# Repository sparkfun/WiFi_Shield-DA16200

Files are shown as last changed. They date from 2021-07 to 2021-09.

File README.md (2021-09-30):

SparkFun WiFi Shield DA16200
========================================

SparkFun WiFi Shield DA16200

[*SparkFun WiFi Shield DA16200 (18567)*](https://www.sparkfun.com/products/18567)

Ultra. Low. Power. Arguably the best three words in the IoT world. SparkFun has teamed up with ARM and Dialog to provide you with this WiFi Shield based around the DA16200 module. The DA16200 is a fully integrated WiFi module with a 40MHz crystal oscillator, 32.768KHz RTC clock, RF Lumped RF filter, 4MB flash memory, and an onboard chip antenna. With the addition of a Qwiic connector, multiple GPIO options, JTAG connectors for deep dive programming, and you've got everything you need to get your R3 layout device ready to set up your next IoT project. 

The SparkFun Qwiic WiFi Shield is ideal for door locks, thermostats, sensors, pet trackers, and other home IoT projects, thanks in part to the multiple sleep modes that allow you to take advantage of current draws as low as 0.2uA-3.5uA.  

Additionally, the DA16200 module's certified WiFi alliance for IEEE802.11b/g/n, WiFi Direct, and WPS functionalities means that it has been approved for use by multiple countries and using the WiFi Alliance transfer policy, each WiFi Certification can be transferred without being tested again. 

Repository Contents
-------------------

* **/Hardware** - Eagle design files (.brd, .sch)

Documentation
--------------
* **[Hookup Guide](https://sparkle.sparkfun.com/sparkle/learn_tutorials/1991)** - Basic hookup guide for the SparkFun WiFi Shield DA16200.

License Information
-------------------

This product is _**open source**_! 

Please review the LICENSE.md file for license information. 

If you have any questions or concerns on licensing, please contact technical support on our [SparkFun forums](https://forum.sparkfun.com/viewforum.php?f=152).

Distributed as-is; no warranty is given.

- Your friends at SparkFun.

_<COLLABORATION CREDIT>_

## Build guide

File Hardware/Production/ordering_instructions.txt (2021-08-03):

panel size, 194x115mm
PCB thickness, 1.6mm
number of layers, 2
soldermask color, Red
silkscreen color, White
oz copper, 1oz
finish, HASL lead free
stencils, top
pcs per panel, 6
min trace width, 0.2032mm / 0.0080in
min drill size, 0.3048mm / 0.0120in

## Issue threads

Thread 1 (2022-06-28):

How to update the firmware?

KeilChris, 2022-06-28:
Hello,
Dialog have released a new FW for the module. Unfortunately, I'm not able to update it on the shield. I have soldered pin headers to "DA16200 PROG" and can kind of connect to the board (I see the serial console), but I cannot use the provided TeraTerm scripts as the required reset never happens. Did anyone update the FW successfully?

KeilChris, 2022-06-28:
Hm, another try today and it worked. Sorry for the confusion!

Closed 2022-06-28.

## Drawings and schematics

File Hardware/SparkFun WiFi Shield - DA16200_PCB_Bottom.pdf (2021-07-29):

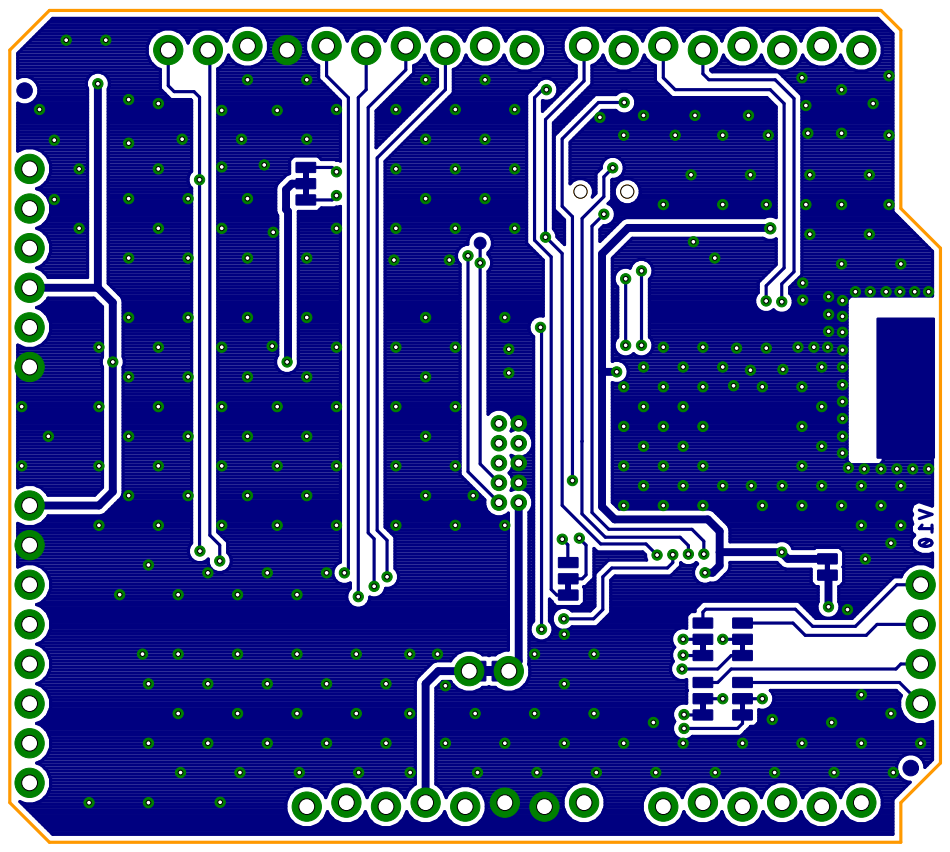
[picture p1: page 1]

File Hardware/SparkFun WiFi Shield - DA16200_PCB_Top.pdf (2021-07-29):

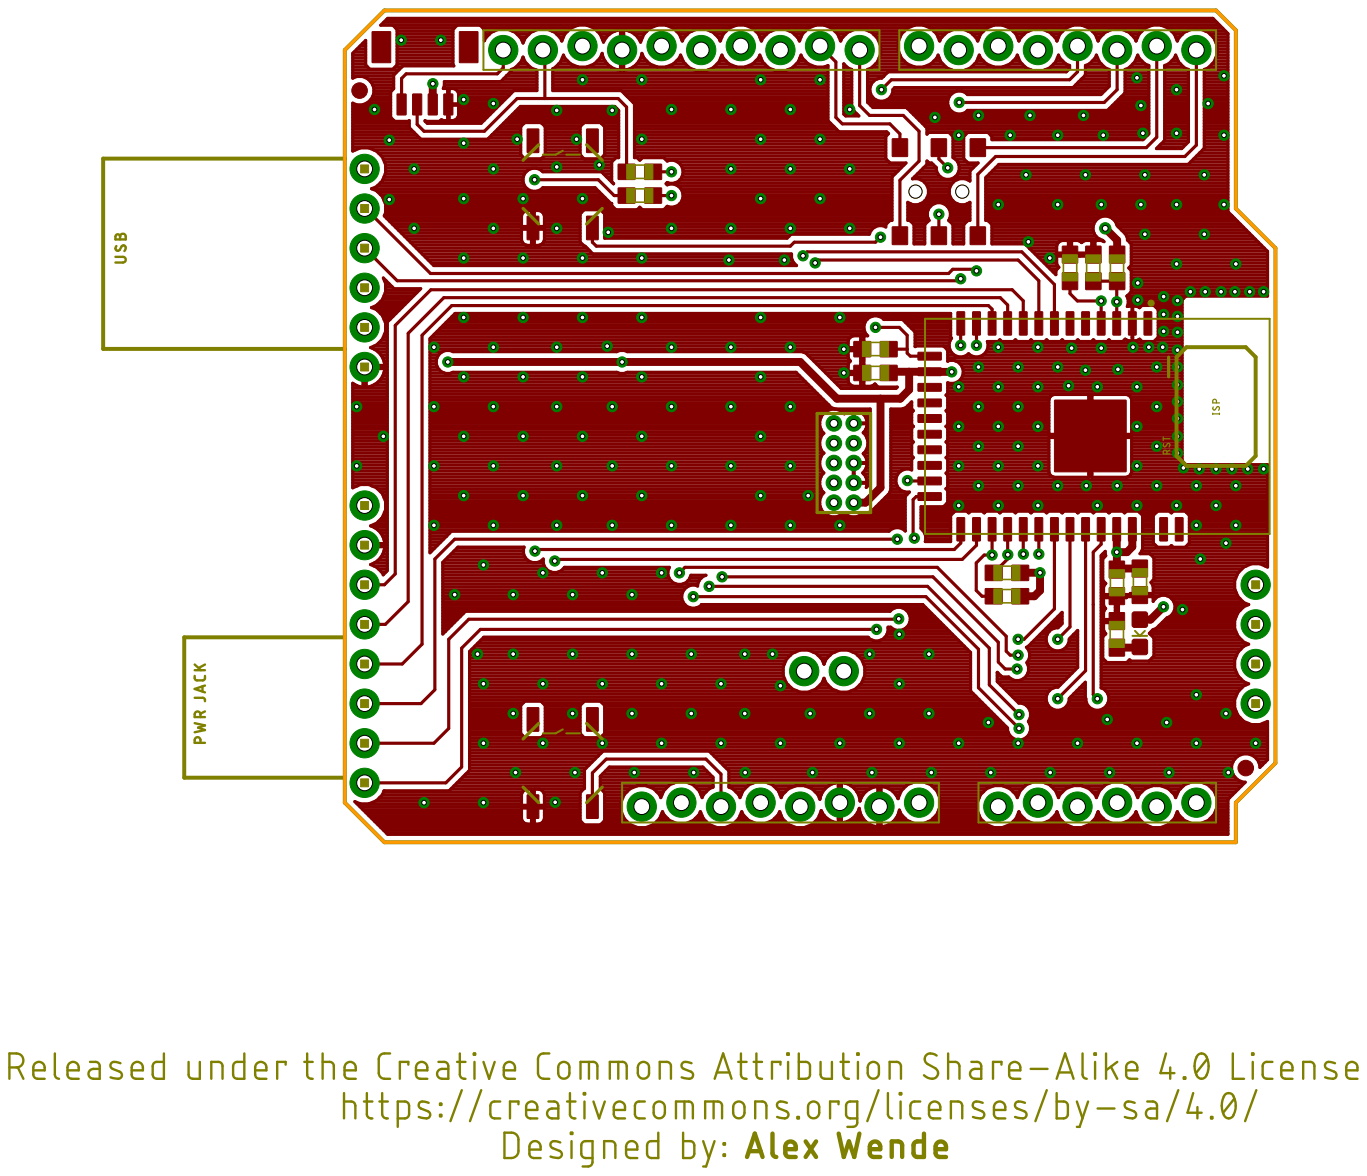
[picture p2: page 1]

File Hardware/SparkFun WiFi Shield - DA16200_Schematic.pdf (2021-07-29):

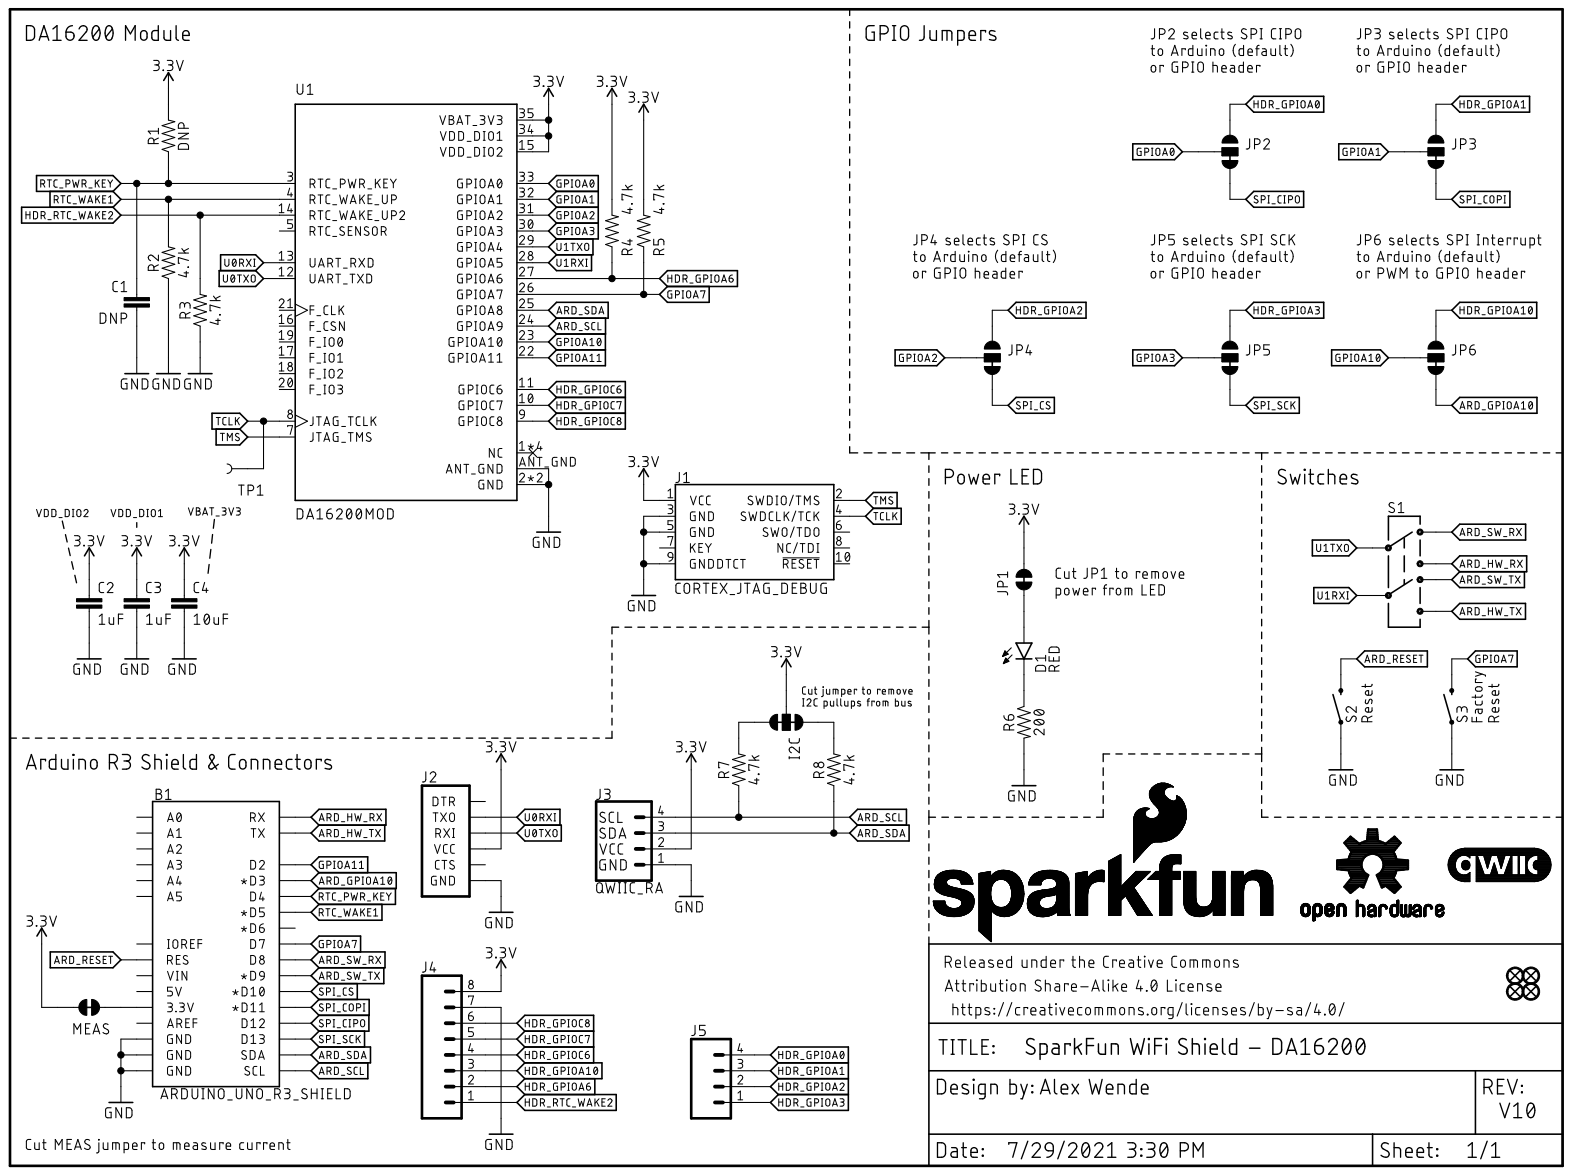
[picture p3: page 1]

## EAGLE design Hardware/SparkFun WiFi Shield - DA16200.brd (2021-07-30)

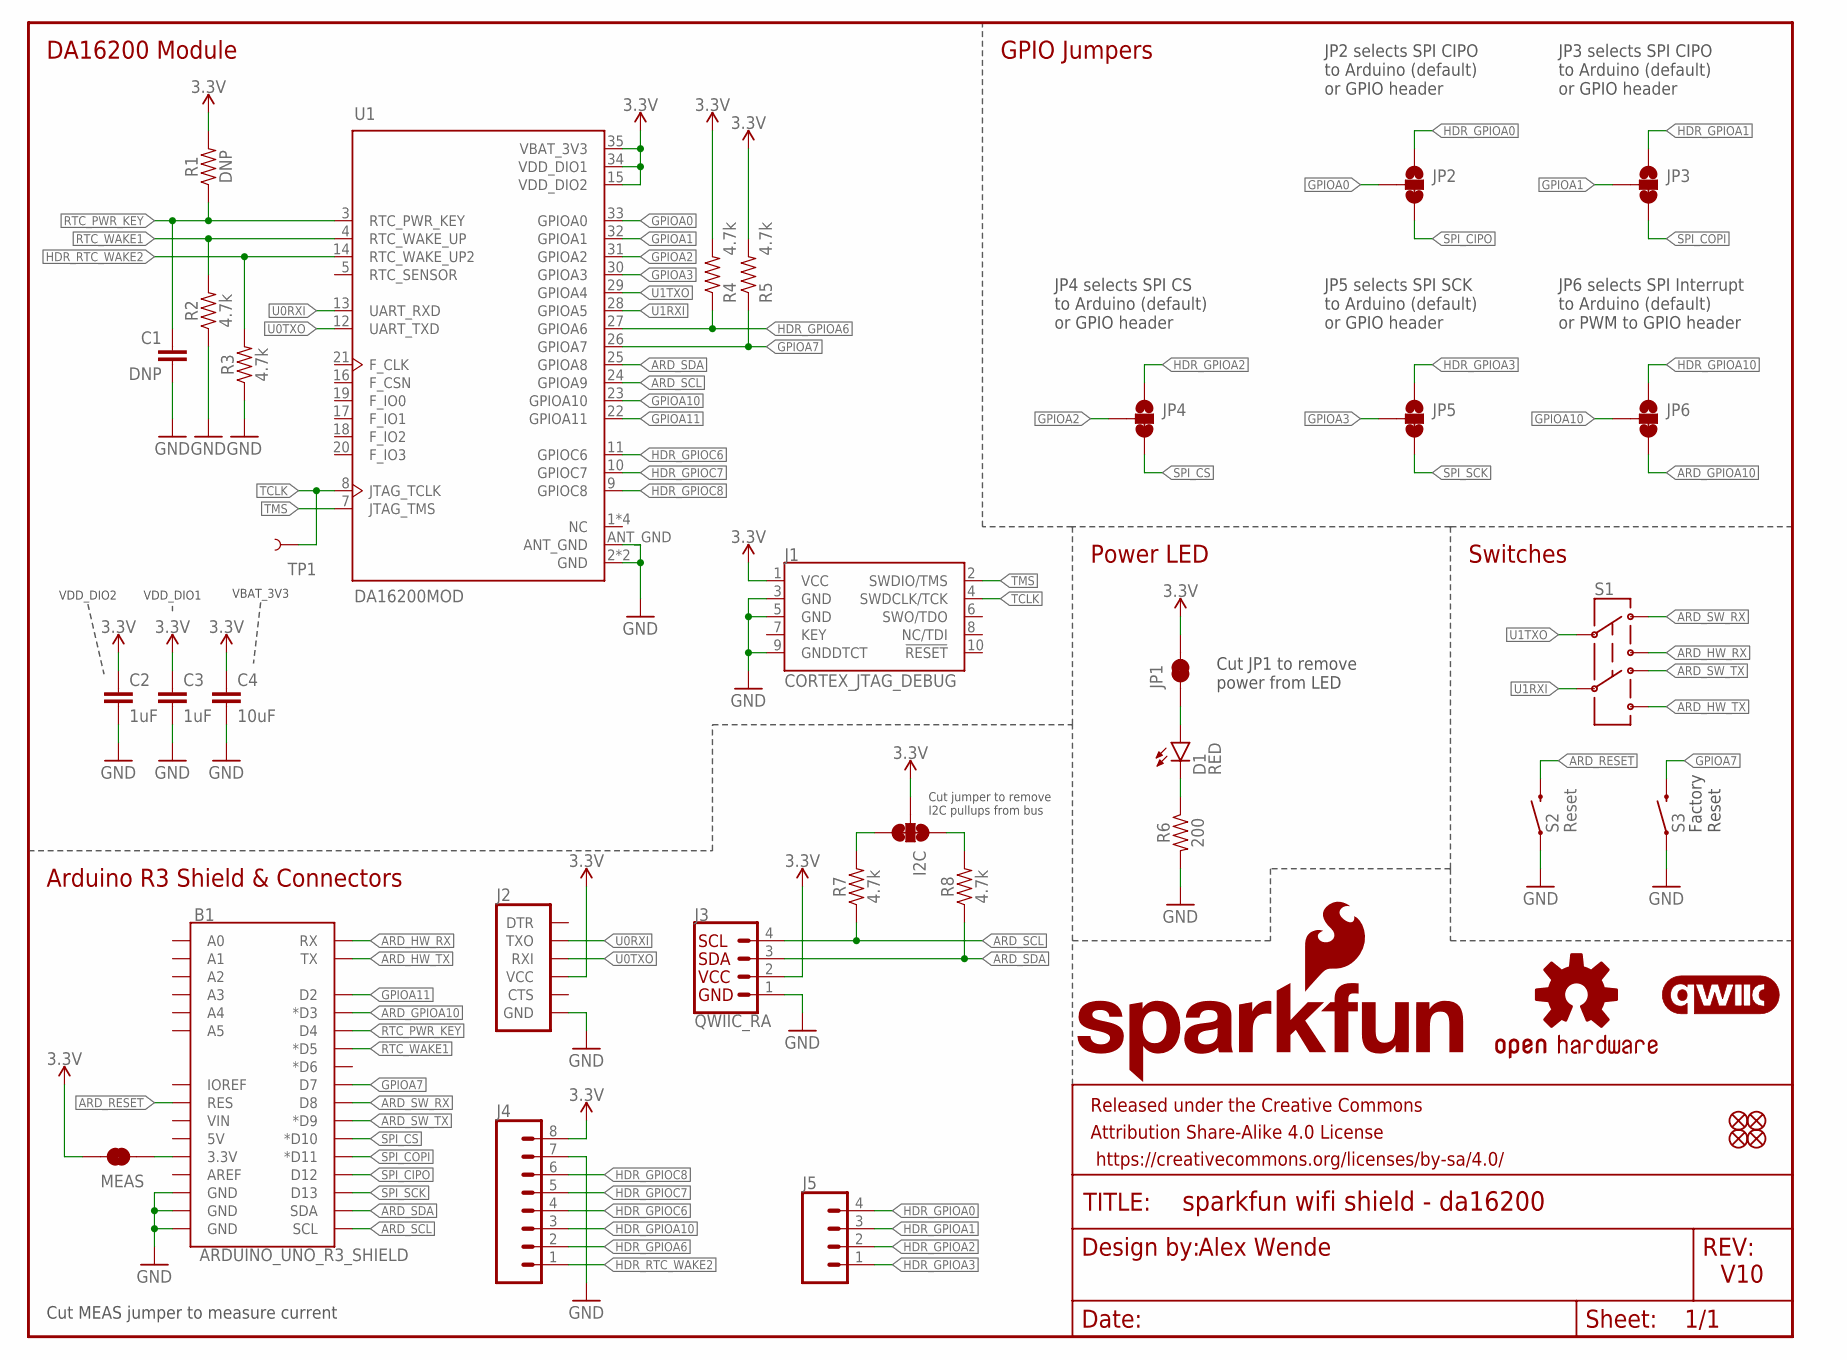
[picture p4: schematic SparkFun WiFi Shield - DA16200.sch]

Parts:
B1: ARDUINO_UNO_R3_SHIELD; UNO_R3_SHIELD_NOLABELS_LOCK
C1: DNP; 0603
C2, C3: 1uF; 0603
C4: 10uF; 0603
D1: RED; LED-0603
FD1, FD2, FD3, FD4: FIDUCIAL1X2; FIDUCIAL-1X2
FRAME1: FRAME-LETTER; CREATIVE_COMMONS
I2C: JUMPER-SMT_3_2-NC_TRACE_SILK; SMT-JUMPER_3_2-NC_TRACE_SILK
J1: CORTEX_JTAG_DEBUG; 2X5-PTH-1.27MM-NO_SILK
J2: 6_PIN_SERIAL_TARGET_NO_SILK; 1X06_NO_SILK
J3: QWIIC_RA; JST04_1MM_RA
J4: CONN_08NO_SILK_DNP; 1X08_NO_SILK
J5: CONN_041X04_NO_SILK; 1X04_NO_SILK
JP1: JUMPER-SMT_2_NC_TRACE_SILK; SMT-JUMPER_2_NC_TRACE_SILK
JP2, JP3, JP4, JP5, JP6: JUMPER-SMT_3_1-NC_TRACE_SILK; SMT-JUMPER_3_1-NC_TRACE_SILK
LOGO1: SFE_LOGO_NAME_FLAME.2_INCH; SFE_LOGO_NAME_FLAME_.2
LOGO2: OSHW-LOGOM; OSHW-LOGO-M
LOGO4: QWIIC_LOGO_5MM; QWIIC_5MM
MEAS: JUMPER-COMBO_2_NC_TRACE; COMBO-JUMPER_2_NC_TRACE
R1: DNP; 0603
R2, R3, R4, R5, R7, R8: 4.7k; 0603
R6: 200; 0603
S1: DPDT; SWITCH_DPDT_SMD_AYZ0202
S2: Reset; TACTILE_SWITCH_SMD_5.2MM
S3: MOMENTARY-SWITCH-SPST-SMD-5.2MM-TALL; TACTILE_SWITCH_SMD_5.2MM
TP1: TEST-POINT3; PAD.03X.03
U1: DA16200MOD; XCVR_DA16200MOD-AAC4WA32

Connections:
3.3V: C2.1, C3.1, C4.1, I2C.2, J1.1 (VCC), J2.4 (VCC), J3.2, J4.8, JP1.2, MEAS.1, MEAS.3 (1), R1.2, R4.2, R5.2, U1.15 (VDD_DIO2), U1.34 (VDD_DIO1), U1.35 (VBAT_3V3)
ARD_GPIOA10: B1.D3 (*D3), JP6.3
ARD_HW_RX: B1.RX, S1.1
ARD_HW_TX: B1.TX, S1.4
ARD_RESET: B1.RES, S2.3 (2)
ARD_SCL: B1.SCL, J3.4, R7.1, U1.24 (GPIOA9)
ARD_SDA: B1.SDA, J3.3, R8.1, U1.25 (GPIOA8)
ARD_SW_RX: B1.D8, S1.3
ARD_SW_TX: B1.D9 (*D9), S1.6
GND: B1.GND@0 (GND), B1.GND@1 (GND), B1.GND@2 (GND), C1.2, C2.2, C3.2, C4.2, J1.3 (GND), J1.5 (GND), J1.9 (GNDDTCT), J2.6 (GND), J3.1, J4.7, R2.1, R3.1, R6.2, S2.1, S3.1, U1.2 (GND), U1.ANT_GND, U1.GND
GPIOA0: JP2.2, U1.33 (GPIOA0)
GPIOA1: JP3.2, U1.32 (GPIOA1)
GPIOA2: JP4.2, U1.31 (GPIOA2)
GPIOA3: JP5.2, U1.30 (GPIOA3)
GPIOA7: B1.D7, R5.1, S3.3 (2), U1.26 (GPIOA7)
GPIOA10: JP6.2, U1.23 (GPIOA10)
GPIOA11: B1.D2, U1.22 (GPIOA11)
HDR_GPIOA0: J5.4, JP2.1
HDR_GPIOA1: J5.3, JP3.1
HDR_GPIOA2: J5.2, JP4.1
HDR_GPIOA3: J5.1, JP5.1
HDR_GPIOA6: J4.2, R4.1, U1.27 (GPIOA6)
HDR_GPIOA10: J4.3, JP6.1
HDR_GPIOC6: J4.4, U1.11 (GPIOC6)
HDR_GPIOC7: J4.5, U1.10 (GPIOC7)
HDR_GPIOC8: J4.6, U1.9 (GPIOC8)
HDR_RTC_WAKE2: J4.1, R3.2, U1.14 (RTC_WAKE_UP2)
unnamed: B1.3.3V, MEAS.2, MEAS.4 (2)
unnamed: D1.A, JP1.1
unnamed: I2C.3, R7.2
unnamed: I2C.1, R8.2
unnamed: D1.C, R6.1
RTC_PWR_KEY: B1.D4, C1.1, R1.1, U1.3 (RTC_PWR_KEY)
RTC_WAKE1: B1.D5 (*D5), R2.2, U1.4 (RTC_WAKE_UP)
SPI_CIPO: B1.D12, JP2.3
SPI_COPI: B1.D11 (*D11), JP3.3
SPI_CS: B1.D10 (*D10), JP4.3
SPI_SCK: B1.D13, JP5.3
TCLK: J1.4 (SWDCLK/TCK), TP1.1, U1.8 (JTAG_TCLK)
TMS: J1.2 (SWDIO/TMS), U1.7 (JTAG_TMS)
U0RXI: J2.3 (TXO), U1.13 (UART_RXD)
U0TXO: J2.2 (RXI), U1.12 (UART_TXD)
U1RXI: S1.5, U1.28 (GPIOA5)
U1TXO: S1.2, U1.29 (GPIOA4)

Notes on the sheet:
Factory Reset
DA16200 Module
Arduino R3 Shield & Connectors
Switches
V10
Alex Wende
VDD_DIO2
VDD_DIO1
VBAT_3V3
Power LED
GPIO Jumpers
Cut JP1 to remove power from LED
JP6 selects SPI Interrupt to Arduino (default) or PWM to GPIO header
Cut MEAS jumper to measure current
Cut jumper to remove I2C pullups from bus
JP2 selects SPI CIPO to Arduino (default) or GPIO header
JP3 selects SPI CIPO to Arduino (default) or GPIO header
JP4 selects SPI CS to Arduino (default) or GPIO header
JP5 selects SPI SCK to Arduino (default) or GPIO header

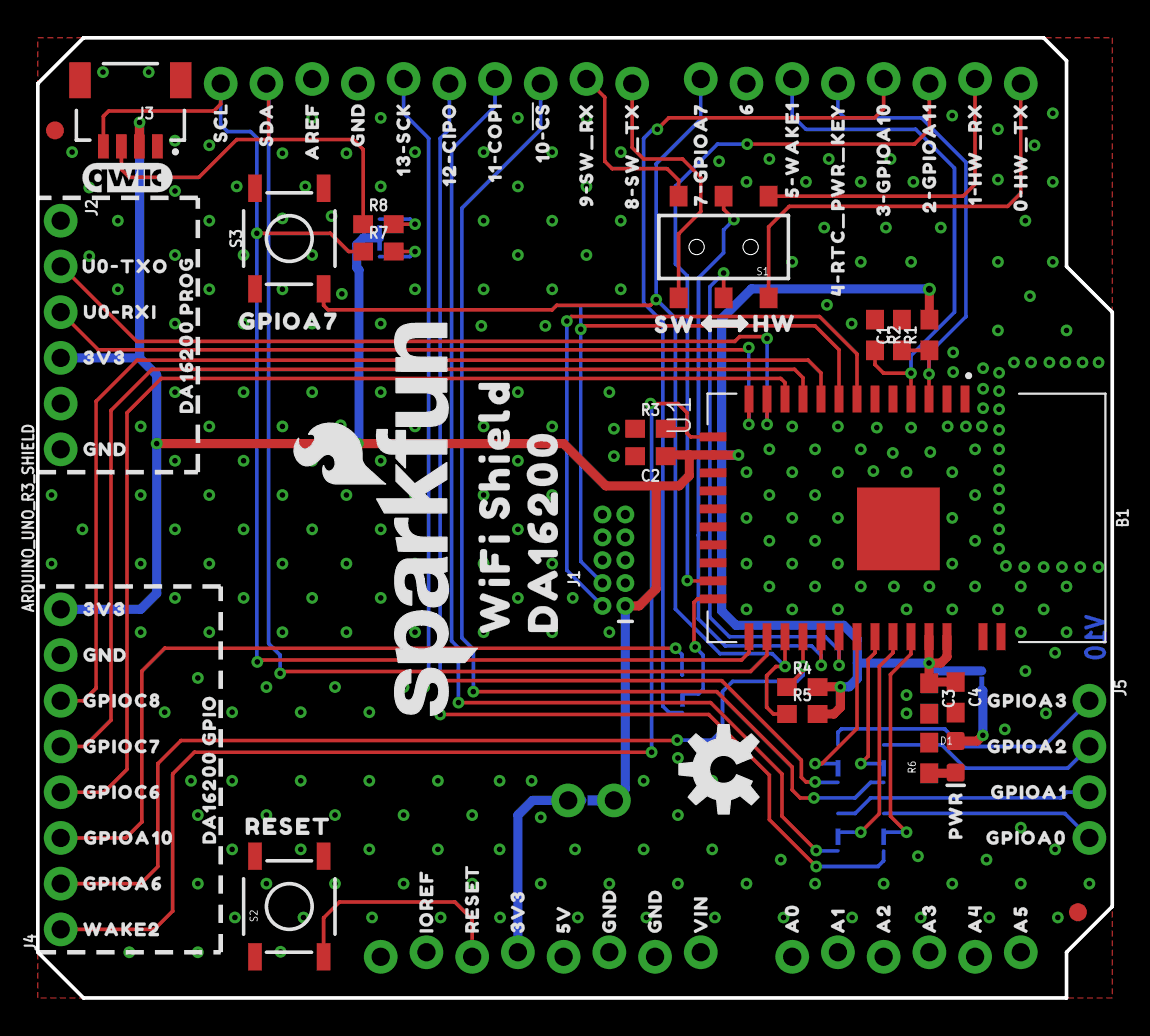
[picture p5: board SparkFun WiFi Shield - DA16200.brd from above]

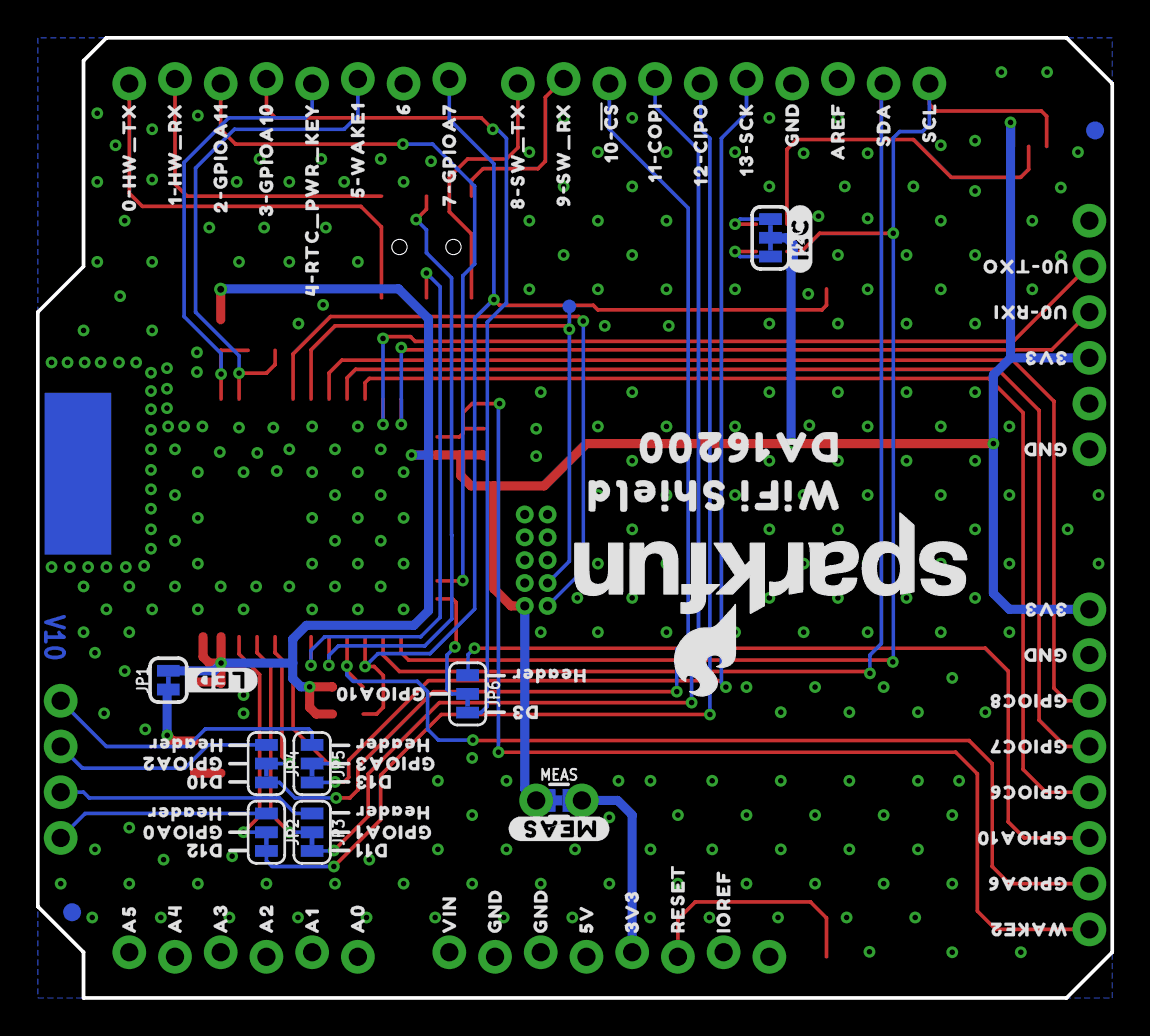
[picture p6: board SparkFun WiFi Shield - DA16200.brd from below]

Board: 2 copper layers, 59.7 x 53.3 mm, 160 parts (75 on the bottom side), 44 nets.

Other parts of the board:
LOGO3: SFE_LOGO_NAME_FLAME.2_INCH; SFE_LOGO_NAME_FLAME_.2
U$1, U$16: IOREF0
U$2, U$19: RESET0
U$3, U$37, U$39, U$41, U$85, U$87: 3V30
U$4, U$55: 5V0
U$5, U$6, U$28, U$40, U$52, U$56, U$57, U$79, U$86, U$88: GND0
U$7, U$58: VIN0
U$8, U$59: A00
U$9, U$60: A10
U$10, U$61: A20
U$11, U$62: A30
U$12, U$63: A40
U$13, U$64: A50
U$14, U$65: 0#HW_TX0
U$15, U$66: 1#HW_RX0
U$17, U$95: GPIOA60
U$18, U$70: 4#RTC_PWR_KEY0
U$20, U$73: 8#SW_TX0
U$21, U$72: 7#GPIOA70
U$23, U$33: 5#WAKE10
U$24, U$75: 10##CS#0
U$25, U$76: 11#COPI0
U$26, U$77: 12#CIPO0
U$27, U$78: 13#SCK0
U$29, U$80: AREF0
U$30, U$81: SDA0
U$31, U$82: SCL0
U$32, U$74: 9#SW_RX0
U$34: GPIOA70
U$35, U$48: WAKE20
U$36: RESET_0
U$38, U$71: 60
U$42: HW0
U$43: SW0
U$44, U$89: GPIOC80
U$45, U$90: GPIOC70
U$46, U$91: GPIOC60
U$47, U$69, U$92: GPIOA100
U$49: #I2C#0
U$50, U$109: 2#GPIOA110
U$51, U$68: 3#GPIOA100
U$53, U$83: U0#TXO0
U$54, U$84: U0#RXI0
U$93, U$115: GPIOA00
U$94, U$114: GPIOA10
U$96: D30
U$97: #LED#0
U$98: #MEAS#0
U$99: PWR0
U$100, U$107: WIFI_SHIELD0
U$101, U$108: DA162000
U$102, U$116: GPIOA20
U$103, U$117: GPIOA30
U$104: DA16200_GPIO0
U$105: DA16200_PROG0
U$106, U$118, U$119, U$120, U$121: HEADER0
U$122: D100
U$123: D110
U$124: D120
U$125: D130

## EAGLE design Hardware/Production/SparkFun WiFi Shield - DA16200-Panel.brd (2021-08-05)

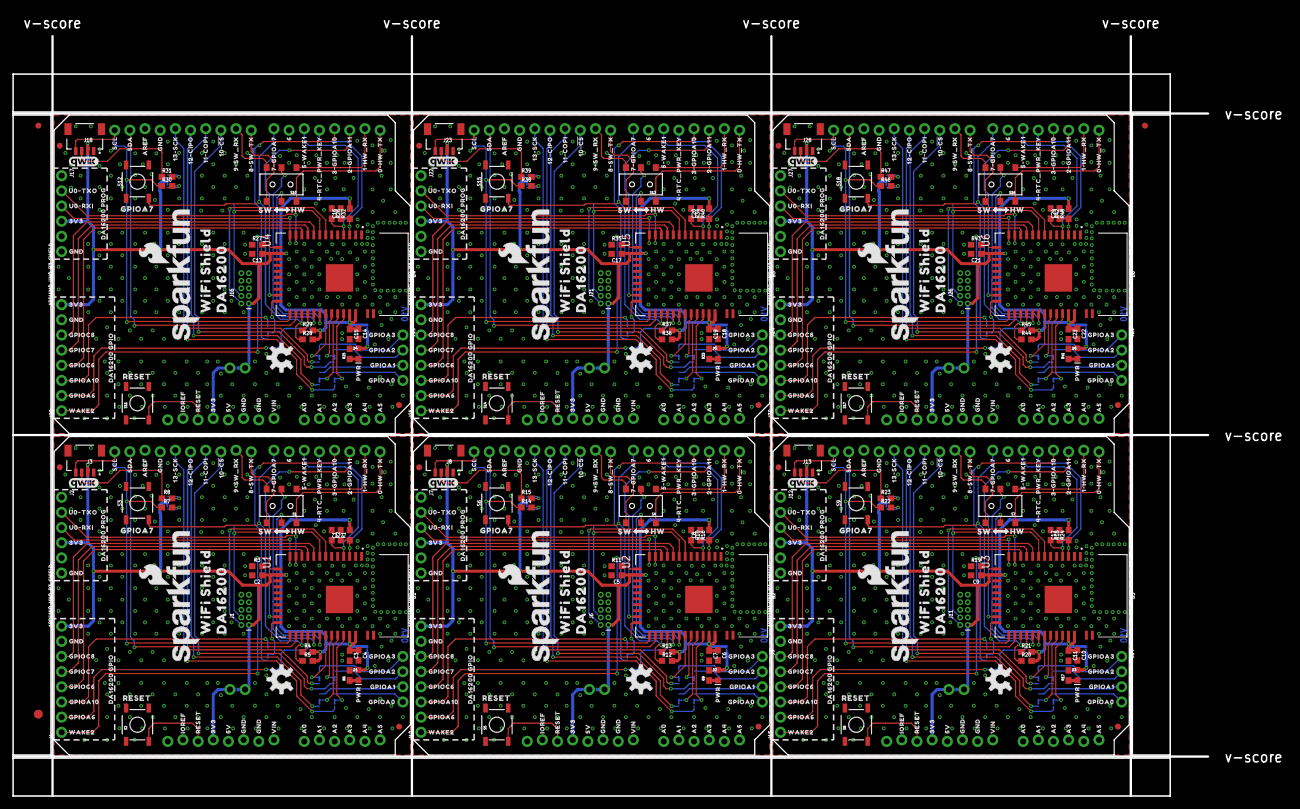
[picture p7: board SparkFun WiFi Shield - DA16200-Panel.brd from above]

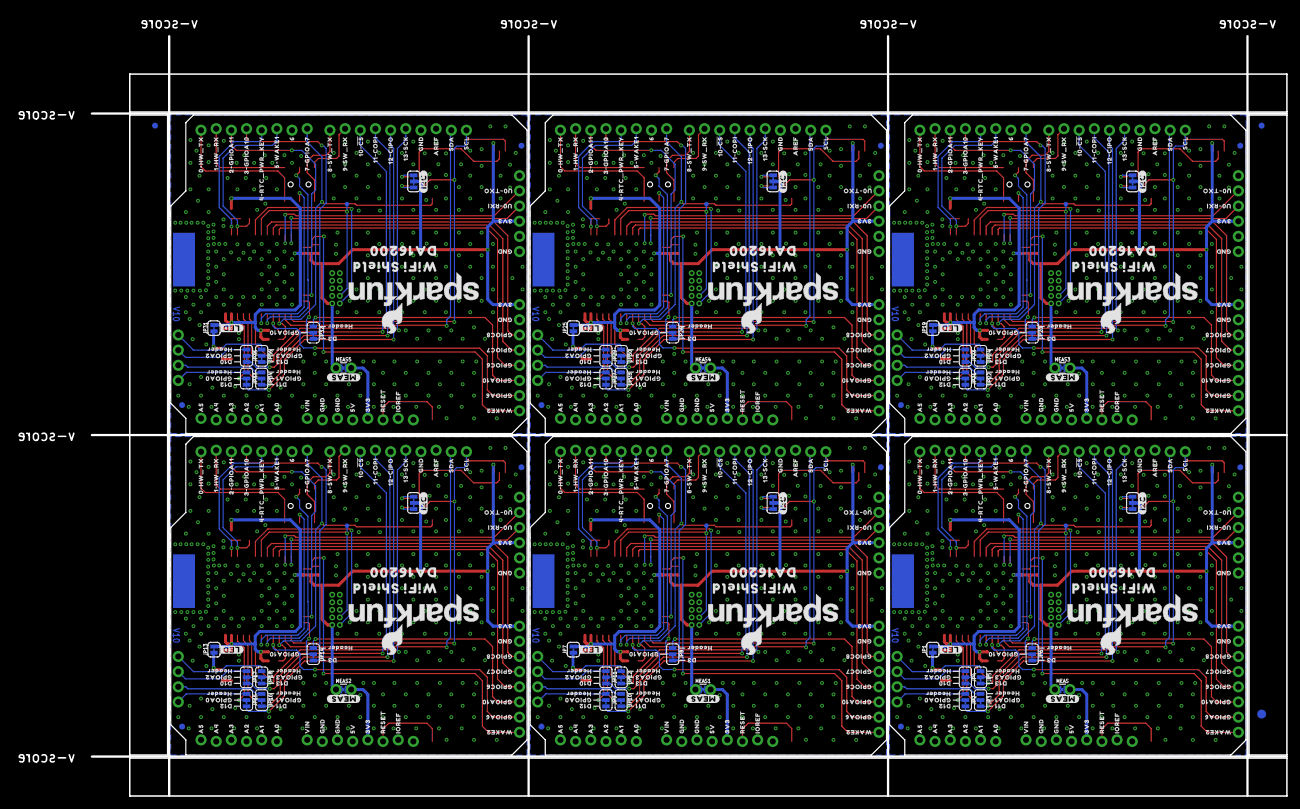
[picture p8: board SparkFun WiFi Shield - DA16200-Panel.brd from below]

Board: 2 copper layers, 200.2 x 127.3 mm, 960 parts (453 on the bottom side), 264 nets.

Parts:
B1, B2, B3, B4, B5, B6: ARDUINO_UNO_R3_SHIELD; UNO_R3_SHIELD_NOLABELS_LOCK
C1, C8, C12, C16, C20, C24: DNP; 0603
C2, C3, C5, C7, C9, C11, C13, C15, C17, C19, C21, C23: 1uF; 0603
C4, C6, C10, C14, C18, C22: 10uF; 0603
D1, D2, D3, D4, D5, D6: RED; LED-0603
E$1, E$2, E$3, E$4: FIDUCIAL-1X2
E$5, E$6: FIDUCIAL-1.5X3
FD1, FD2, FD3, FD4, FD5, FD6, FD7, FD8, FD9, FD10, FD11, FD12, FD13, FD14, FD15, FD16, FD17, FD18, FD19, FD20, FD21, FD22, FD23, FD24: FIDUCIAL1X2; FIDUCIAL-1X2
I2C, I2C1, I2C2, I2C3, I2C4, I2C5: SMT-JUMPER_3_2-NC_TRACE_SILK
J1, J6, J11, J16, J21, J26: CORTEX_JTAG_DEBUG; 2X5-PTH-1.27MM-NO_SILK
J2, J7, J12, J17, J22, J27: 1X06_NO_SILK
J3, J8, J13, J18, J23, J28: QWIIC_RA; JST04_1MM_RA
J4, J10, J15, J20, J25, J30: 1X08_NO_SILK
J5, J9, J14, J19, J24, J29: 1X04_NO_SILK
JP1, JP7, JP13, JP19, JP25, JP31: SMT-JUMPER_2_NC_TRACE_SILK
JP2, JP3, JP4, JP5, JP6, JP8, JP9, JP10, JP11, JP12, JP14, JP15, JP16, JP17, JP18, JP20, JP21, JP22, JP23, JP24, JP26, JP27, JP28, JP29, JP30, JP32, JP33, JP34, JP35, JP36: SMT-JUMPER_3_1-NC_TRACE_SILK
LOGO1, LOGO3, LOGO5, LOGO7, LOGO9, LOGO11, LOGO13, LOGO15, LOGO17, LOGO19, LOGO21, LOGO23: SFE_LOGO_NAME_FLAME.2_INCH; SFE_LOGO_NAME_FLAME_.2
LOGO2, LOGO6, LOGO10, LOGO14, LOGO18, LOGO22: OSHW-LOGOM; OSHW-LOGO-M
LOGO4, LOGO8, LOGO12, LOGO16, LOGO20, LOGO24: QWIIC_LOGO_5MM; QWIIC_5MM
MEAS, MEAS1, MEAS2, MEAS3, MEAS4, MEAS5: COMBO-JUMPER_2_NC_TRACE
R1, R16, R24, R32, R40, R48: DNP; 0603
R2, R3, R4, R5, R7, R8, R10, R11, R12, R13, R14, R15, R18, R19, R20, R21, R22, R23, R26, R27, R28, R29, R30, R31, R34, R35, R36, R37, R38, R39, R42, R43, R44, R45, R46, R47: 4.7k; 0603
R6, R9, R17, R25, R33, R41: 200; 0603
S1, S4, S7, S10, S13, S16: DPDT; SWITCH_DPDT_SMD_AYZ0202
S2, S5, S8, S11, S14, S17: Reset; TACTILE_SWITCH_SMD_5.2MM
S3, S6, S9, S12, S15, S18: TACTILE_SWITCH_SMD_5.2MM
TP1, TP2, TP3, TP4, TP5, TP6: PAD.03X.03
U1, U2, U3, U4, U5, U6: DA16200MOD; XCVR_DA16200MOD-AAC4WA32
U$1, U$16, U$22, U$162, U$239, U$281, U$358, U$400, U$477, U$519, U$596, U$638: IOREF0
U$2, U$19, U$67, U$163, U$240, U$282, U$359, U$401, U$478, U$520, U$597, U$639: RESET0
U$3, U$37, U$39, U$41, U$85, U$87, U$110, U$152, U$155, U$164, U$191, U$193, U$241, U$271, U$274, U$283, U$310, U$312, U$360, U$390, U$393, U$402, U$429, U$431, U$479, U$509, U$512, U$521, U$548, U$550, U$598, U$628, U$631, U$640, U$667, U$669: 3V30
U$4, U$55, U$111, U$165, U$242, U$284, U$361, U$403, U$480, U$522, U$599, U$641: 5V0
U$5, U$6, U$28, U$40, U$52, U$56, U$57, U$79, U$86, U$88, U$112, U$113, U$140, U$153, U$154, U$166, U$167, U$185, U$192, U$194, U$243, U$244, U$259, U$272, U$273, U$285, U$286, U$304, U$311, U$313, U$362, U$363, U$378, U$391, U$392, U$404, U$405, U$423, U$430, U$432, U$481, U$482, U$497, U$510, U$511, U$523, U$524, U$542, U$549, U$551, U$600, U$601, U$616, U$629, U$630, U$642, U$643, U$661, U$668, U$670: GND0
U$7, U$58, U$126, U$168, U$245, U$287, U$364, U$406, U$483, U$525, U$602, U$644: VIN0
U$8, U$59, U$127, U$169, U$246, U$288, U$365, U$407, U$484, U$526, U$603, U$645: A00
U$9, U$60, U$128, U$170, U$247, U$289, U$366, U$408, U$485, U$527, U$604, U$646: A10
U$10, U$61, U$129, U$171, U$248, U$290, U$367, U$409, U$486, U$528, U$605, U$647: A20
U$11, U$62, U$130, U$172, U$249, U$291, U$368, U$410, U$487, U$529, U$606, U$648: A30
U$12, U$63, U$131, U$173, U$250, U$292, U$369, U$411, U$488, U$530, U$607, U$649: A40
U$13, U$64, U$132, U$174, U$251, U$293, U$370, U$412, U$489, U$531, U$608, U$650: A50
U$14, U$65, U$133, U$175, U$252, U$294, U$371, U$413, U$490, U$532, U$609, U$651: 0#HW_TX0
U$15, U$66, U$134, U$176, U$253, U$295, U$372, U$414, U$491, U$533, U$610, U$652: 1#HW_RX0
U$17, U$95, U$158, U$199, U$277, U$318, U$396, U$437, U$515, U$556, U$634, U$675: GPIOA60
U$18, U$70, U$231, U$234, U$350, U$353, U$469, U$472, U$588, U$591, U$707, U$710: 4#RTC_PWR_KEY0
U$20, U$73, U$159, U$179, U$278, U$298, U$397, U$417, U$516, U$536, U$635, U$655: 8#SW_TX0
U$21, U$72, U$135, U$178, U$254, U$297, U$373, U$416, U$492, U$535, U$611, U$654: 7#GPIOA70
U$23, U$33, U$232, U$233, U$351, U$352, U$470, U$471, U$589, U$590, U$708, U$709: 5#WAKE10
U$24, U$75, U$136, U$181, U$255, U$300, U$374, U$419, U$493, U$538, U$612, U$657: 10##CS#0
U$25, U$76, U$137, U$182, U$256, U$301, U$375, U$420, U$494, U$539, U$613, U$658: 11#COPI0
U$26, U$77, U$138, U$183, U$257, U$302, U$376, U$421, U$495, U$540, U$614, U$659: 12#CIPO0
U$27, U$78, U$139, U$184, U$258, U$303, U$377, U$422, U$496, U$541, U$615, U$660: 13#SCK0
U$29, U$80, U$141, U$186, U$260, U$305, U$379, U$424, U$498, U$543, U$617, U$662: AREF0
U$30, U$81, U$142, U$187, U$261, U$306, U$380, U$425, U$499, U$544, U$618, U$663: SDA0
U$31, U$82, U$143, U$188, U$262, U$307, U$381, U$426, U$500, U$545, U$619, U$664: SCL0
U$32, U$74, U$160, U$180, U$279, U$299, U$398, U$418, U$517, U$537, U$636, U$656: 9#SW_RX0
U$34, U$144, U$263, U$382, U$501, U$620: GPIOA70
U$35, U$48, U$235, U$236, U$354, U$355, U$473, U$474, U$592, U$593, U$711, U$712: WAKE20
U$36, U$151, U$270, U$389, U$508, U$627: RESET_0
U$38, U$71, U$161, U$177, U$280, U$296, U$399, U$415, U$518, U$534, U$637, U$653: 60
U$42, U$156, U$275, U$394, U$513, U$632: HW0
U$43, U$157, U$276, U$395, U$514, U$633: SW0
U$44, U$89, U$145, U$195, U$264, U$314, U$383, U$433, U$502, U$552, U$621, U$671: GPIOC80
U$45, U$90, U$146, U$196, U$265, U$315, U$384, U$434, U$503, U$553, U$622, U$672: GPIOC70
U$46, U$91, U$147, U$197, U$266, U$316, U$385, U$435, U$504, U$554, U$623, U$673: GPIOC60
U$47, U$69, U$92, U$148, U$198, U$207, U$267, U$317, U$326, U$386, U$436, U$445, U$505, U$555, U$564, U$624, U$674, U$683: GPIOA100
U$49, U$214, U$333, U$452, U$571, U$690: #I2C#0
U$50, U$109, U$237, U$238, U$356, U$357, U$475, U$476, U$594, U$595, U$713, U$714: 2#GPIOA110
U$51, U$68, U$205, U$206, U$324, U$325, U$443, U$444, U$562, U$563, U$681, U$682: 3#GPIOA100
U$53, U$83, U$149, U$189, U$268, U$308, U$387, U$427, U$506, U$546, U$625, U$665: U0#TXO0
U$54, U$84, U$150, U$190, U$269, U$309, U$388, U$428, U$507, U$547, U$626, U$666: U0#RXI0
U$93, U$115, U$216, U$227, U$335, U$346, U$454, U$465, U$573, U$584, U$692, U$703: GPIOA00
U$94, U$114, U$215, U$228, U$334, U$347, U$453, U$466, U$572, U$585, U$691, U$704: GPIOA10
U$96, U$208, U$327, U$446, U$565, U$684: D30
U$97, U$200, U$319, U$438, U$557, U$676: #LED#0
U$98, U$201, U$320, U$439, U$558, U$677: #MEAS#0
U$99, U$202, U$321, U$440, U$559, U$678: PWR0
U$100, U$107, U$210, U$212, U$329, U$331, U$448, U$450, U$567, U$569, U$686, U$688: WIFI_SHIELD0
U$101, U$108, U$211, U$213, U$330, U$332, U$449, U$451, U$568, U$570, U$687, U$689: DA162000
U$102, U$116, U$217, U$229, U$336, U$348, U$455, U$467, U$574, U$586, U$693, U$705: GPIOA20
U$103, U$117, U$218, U$230, U$337, U$349, U$456, U$468, U$575, U$587, U$694, U$706: GPIOA30
U$104, U$203, U$322, U$441, U$560, U$679: DA16200_GPIO0
U$105, U$204, U$323, U$442, U$561, U$680: DA16200_PROG0
U$106, U$118, U$119, U$120, U$121, U$209, U$219, U$220, U$221, U$222, U$328, U$338, U$339, U$340, U$341, U$447, U$457, U$458, U$459, U$460, U$566, U$576, U$577, U$578, U$579, U$685, U$695, U$696, U$697, U$698: HEADER0
U$122, U$223, U$342, U$461, U$580, U$699: D100
U$123, U$224, U$343, U$462, U$581, U$700: D110
U$124, U$225, U$344, U$463, U$582, U$701: D120
U$125, U$226, U$345, U$464, U$583, U$702: D130

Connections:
3.3V: C2.1, C3.1, C4.1, I2C.2, J1.1, J2.4, J3.2, J4.8, JP1.2, MEAS.1, MEAS.3, R1.2, R4.2, R5.2, U1.15, U1.34, U1.35
3.3V1: C5.1, C6.1, C7.1, I2C1.2, J6.1, J7.4, J8.2, J10.8, JP7.2, MEAS1.1, MEAS1.3, R12.2, R13.2, R16.2, U2.15, U2.34, U2.35
3.3V2: C9.1, C10.1, C11.1, I2C2.2, J11.1, J12.4, J13.2, J15.8, JP13.2, MEAS2.1, MEAS2.3, R20.2, R21.2, R24.2, U3.15, U3.34, U3.35
3.3V3: C13.1, C14.1, C15.1, I2C3.2, J16.1, J17.4, J18.2, J20.8, JP19.2, MEAS3.1, MEAS3.3, R28.2, R29.2, R32.2, U4.15, U4.34, U4.35
3.3V4: C17.1, C18.1, C19.1, I2C4.2, J21.1, J22.4, J23.2, J25.8, JP25.2, MEAS4.1, MEAS4.3, R36.2, R37.2, R40.2, U5.15, U5.34, U5.35
3.3V5: C21.1, C22.1, C23.1, I2C5.2, J26.1, J27.4, J28.2, J30.8, JP31.2, MEAS5.1, MEAS5.3, R44.2, R45.2, R48.2, U6.15, U6.34, U6.35
ARD_GPIOA1: B2.D3, JP8.3
ARD_GPIOA2: B3.D3, JP14.3
ARD_GPIOA3: B4.D3, JP20.3
ARD_GPIOA4: B5.D3, JP26.3
ARD_GPIOA5: B6.D3, JP32.3
ARD_GPIOA10: B1.D3, JP6.3
ARD_HW_RX: B1.RX, S1.1
ARD_HW_RX1: B2.RX, S4.1
ARD_HW_RX2: B3.RX, S7.1
ARD_HW_RX3: B4.RX, S10.1
ARD_HW_RX4: B5.RX, S13.1
ARD_HW_RX5: B6.RX, S16.1
ARD_HW_TX: B1.TX, S1.4
ARD_HW_TX1: B2.TX, S4.4
ARD_HW_TX2: B3.TX, S7.4
ARD_HW_TX3: B4.TX, S10.4
ARD_HW_TX4: B5.TX, S13.4
ARD_HW_TX5: B6.TX, S16.4
ARD_RESET: B1.RES, S2.3
ARD_RESET1: B2.RES, S5.3
ARD_RESET2: B3.RES, S8.3
ARD_RESET3: B4.RES, S11.3
ARD_RESET4: B5.RES, S14.3
ARD_RESET5: B6.RES, S17.3
ARD_SCL: B1.SCL, J3.4, R7.1, U1.24
ARD_SCL1: B2.SCL, J8.4, R14.1, U2.24
ARD_SCL2: B3.SCL, J13.4, R22.1, U3.24
ARD_SCL3: B4.SCL, J18.4, R30.1, U4.24
ARD_SCL4: B5.SCL, J23.4, R38.1, U5.24
ARD_SCL5: B6.SCL, J28.4, R46.1, U6.24
ARD_SDA: B1.SDA, J3.3, R8.1, U1.25
ARD_SDA1: B2.SDA, J8.3, R15.1, U2.25
ARD_SDA2: B3.SDA, J13.3, R23.1, U3.25
ARD_SDA3: B4.SDA, J18.3, R31.1, U4.25
ARD_SDA4: B5.SDA, J23.3, R39.1, U5.25
ARD_SDA5: B6.SDA, J28.3, R47.1, U6.25
ARD_SW_RX: B1.D8, S1.3
ARD_SW_RX1: B2.D8, S4.3
ARD_SW_RX2: B3.D8, S7.3
ARD_SW_RX3: B4.D8, S10.3
ARD_SW_RX4: B5.D8, S13.3
ARD_SW_RX5: B6.D8, S16.3
ARD_SW_TX: B1.D9, S1.6
ARD_SW_TX1: B2.D9, S4.6
ARD_SW_TX2: B3.D9, S7.6
ARD_SW_TX3: B4.D9, S10.6
ARD_SW_TX4: B5.D9, S13.6
ARD_SW_TX5: B6.D9, S16.6
GND: B1.GND@0, B1.GND@1, B1.GND@2, C1.2, C2.2, C3.2, C4.2, J1.3, J1.5, J1.9, J2.6, J3.1, J4.7, R2.1, R3.1, R6.2, S2.1, S3.1, U1.2, U1.ANT_GND, U1.GND
GND1: B2.GND@0, B2.GND@1, B2.GND@2, C5.2, C6.2, C7.2, C8.2, J6.3, J6.5, J6.9, J7.6, J8.1, J10.7, R9.2, R10.1, R11.1, S5.1, S6.1, U2.2, U2.ANT_GND, U2.GND
GND2: B3.GND@0, B3.GND@1, B3.GND@2, C9.2, C10.2, C11.2, C12.2, J11.3, J11.5, J11.9, J12.6, J13.1, J15.7, R17.2, R18.1, R19.1, S8.1, S9.1, U3.2, U3.ANT_GND, U3.GND
GND3: B4.GND@0, B4.GND@1, B4.GND@2, C13.2, C14.2, C15.2, C16.2, J16.3, J16.5, J16.9, J17.6, J18.1, J20.7, R25.2, R26.1, R27.1, S11.1, S12.1, U4.2, U4.ANT_GND, U4.GND
GND4: B5.GND@0, B5.GND@1, B5.GND@2, C17.2, C18.2, C19.2, C20.2, J21.3, J21.5, J21.9, J22.6, J23.1, J25.7, R33.2, R34.1, R35.1, S14.1, S15.1, U5.2, U5.ANT_GND, U5.GND
GND5: B6.GND@0, B6.GND@1, B6.GND@2, C21.2, C22.2, C23.2, C24.2, J26.3, J26.5, J26.9, J27.6, J28.1, J30.7, R41.2, R42.1, R43.1, S17.1, S18.1, U6.2, U6.ANT_GND, U6.GND
GPIOA0: JP2.2, U1.33
GPIOA1: JP3.2, U1.32
GPIOA2: JP4.2, U1.31
GPIOA3: JP5.2, U1.30
GPIOA4: B2.D7, R12.1, S6.3, U2.26
GPIOA5: JP8.2, U2.23
GPIOA6: B2.D2, U2.22
GPIOA7: B1.D7, R5.1, S3.3, U1.26
GPIOA8: JP9.2, U2.33
GPIOA9: JP10.2, U2.32
GPIOA10: JP6.2, U1.23
GPIOA11: B1.D2, U1.22
GPIOA12: JP11.2, U2.31
GPIOA13: JP12.2, U2.30
GPIOA14: B3.D7, R20.1, S9.3, U3.26
GPIOA15: JP14.2, U3.23
GPIOA16: B3.D2, U3.22
GPIOA17: JP15.2, U3.33
GPIOA18: JP16.2, U3.32
GPIOA19: JP17.2, U3.31
GPIOA20: JP18.2, U3.30
GPIOA21: B4.D7, R28.1, S12.3, U4.26
GPIOA22: JP20.2, U4.23
GPIOA23: B4.D2, U4.22
GPIOA24: JP21.2, U4.33
GPIOA25: JP22.2, U4.32
GPIOA26: JP23.2, U4.31
GPIOA27: JP24.2, U4.30
GPIOA28: B5.D7, R36.1, S15.3, U5.26
GPIOA29: JP26.2, U5.23
GPIOA30: B5.D2, U5.22
GPIOA31: JP27.2, U5.33
GPIOA32: JP28.2, U5.32
GPIOA33: JP29.2, U5.31
GPIOA34: JP30.2, U5.30
GPIOA35: B6.D7, R44.1, S18.3, U6.26
GPIOA36: JP32.2, U6.23
GPIOA37: B6.D2, U6.22
GPIOA38: JP33.2, U6.33
GPIOA39: JP34.2, U6.32
GPIOA40: JP35.2, U6.31
GPIOA41: JP36.2, U6.30
HDR_GPIOA0: J5.4, JP2.1
HDR_GPIOA1: J5.3, JP3.1
HDR_GPIOA2: J5.2, JP4.1
HDR_GPIOA3: J5.1, JP5.1
HDR_GPIOA4: J9.4, JP9.1
HDR_GPIOA5: J9.3, JP10.1
HDR_GPIOA6: J4.2, R4.1, U1.27
HDR_GPIOA7: J10.3, JP8.1
HDR_GPIOA8: J10.2, R13.1, U2.27
HDR_GPIOA9: J9.2, JP11.1
HDR_GPIOA10: J4.3, JP6.1
HDR_GPIOA11: J9.1, JP12.1
HDR_GPIOA12: J14.4, JP15.1
HDR_GPIOA13: J14.3, JP16.1
HDR_GPIOA14: J15.3, JP14.1
HDR_GPIOA15: J15.2, R21.1, U3.27
HDR_GPIOA16: J14.2, JP17.1
HDR_GPIOA17: J14.1, JP18.1
HDR_GPIOA18: J19.4, JP21.1
HDR_GPIOA19: J19.3, JP22.1
HDR_GPIOA20: J20.3, JP20.1
HDR_GPIOA21: J20.2, R29.1, U4.27
HDR_GPIOA22: J19.2, JP23.1
HDR_GPIOA23: J19.1, JP24.1
HDR_GPIOA24: J24.4, JP27.1
HDR_GPIOA25: J24.3, JP28.1
HDR_GPIOA26: J25.3, JP26.1
HDR_GPIOA27: J25.2, R37.1, U5.27
HDR_GPIOA28: J24.2, JP29.1
HDR_GPIOA29: J24.1, JP30.1
HDR_GPIOA30: J29.4, JP33.1
HDR_GPIOA31: J29.3, JP34.1
HDR_GPIOA32: J30.3, JP32.1
HDR_GPIOA33: J30.2, R45.1, U6.27
HDR_GPIOA34: J29.2, JP35.1
HDR_GPIOA35: J29.1, JP36.1
HDR_GPIOC1: J10.4, U2.11
HDR_GPIOC2: J10.5, U2.10
HDR_GPIOC3: J10.6, U2.9
HDR_GPIOC4: J15.4, U3.11
HDR_GPIOC5: J15.5, U3.10
HDR_GPIOC6: J4.4, U1.11
HDR_GPIOC7: J4.5, U1.10
HDR_GPIOC8: J4.6, U1.9
HDR_GPIOC9: J15.6, U3.9
HDR_GPIOC10: J20.4, U4.11
HDR_GPIOC11: J20.5, U4.10
HDR_GPIOC12: J20.6, U4.9
HDR_GPIOC13: J25.4, U5.11
HDR_GPIOC14: J25.5, U5.10
HDR_GPIOC15: J25.6, U5.9
HDR_GPIOC16: J30.4, U6.11
HDR_GPIOC17: J30.5, U6.10
HDR_GPIOC18: J30.6, U6.9
HDR_RTC_WAKE1: J10.1, R11.2, U2.14
HDR_RTC_WAKE2: J4.1, R3.2, U1.14
HDR_RTC_WAKE3: J15.1, R19.2, U3.14
HDR_RTC_WAKE4: J20.1, R27.2, U4.14
HDR_RTC_WAKE5: J25.1, R35.2, U5.14
HDR_RTC_WAKE6: J30.1, R43.2, U6.14
unnamed: B1.3.3V, MEAS.2, MEAS.4
unnamed: D1.A, JP1.1
unnamed: I2C.3, R7.2
unnamed: I2C.1, R8.2
unnamed: D1.C, R6.1
unnamed: D2.C, R9.1
unnamed: B2.3.3V, MEAS1.2, MEAS1.4
unnamed: D2.A, JP7.1
unnamed: I2C1.3, R14.2
unnamed: I2C1.1, R15.2
unnamed: D3.C, R17.1
unnamed: B3.3.3V, MEAS2.2, MEAS2.4
unnamed: D3.A, JP13.1
unnamed: I2C2.3, R22.2
unnamed: I2C2.1, R23.2
unnamed: D4.C, R25.1
unnamed: B4.3.3V, MEAS3.2, MEAS3.4
unnamed: D4.A, JP19.1
unnamed: I2C3.3, R30.2
unnamed: I2C3.1, R31.2
unnamed: D5.C, R33.1
unnamed: B5.3.3V, MEAS4.2, MEAS4.4
unnamed: D5.A, JP25.1
unnamed: I2C4.3, R38.2
unnamed: I2C4.1, R39.2
unnamed: D6.C, R41.1
unnamed: B6.3.3V, MEAS5.2, MEAS5.4
unnamed: D6.A, JP31.1
unnamed: I2C5.3, R46.2
unnamed: I2C5.1, R47.2
RTC_PWR_KEY: B1.D4, C1.1, R1.1, U1.3
RTC_PWR_KEY1: B2.D4, C8.1, R16.1, U2.3
RTC_PWR_KEY2: B3.D4, C12.1, R24.1, U3.3
RTC_PWR_KEY3: B4.D4, C16.1, R32.1, U4.3
RTC_PWR_KEY4: B5.D4, C20.1, R40.1, U5.3
RTC_PWR_KEY5: B6.D4, C24.1, R48.1, U6.3
RTC_WAKE1: B1.D5, R2.2, U1.4
RTC_WAKE2: B2.D5, R10.2, U2.4
RTC_WAKE3: B3.D5, R18.2, U3.4
RTC_WAKE4: B4.D5, R26.2, U4.4
RTC_WAKE5: B5.D5, R34.2, U5.4
RTC_WAKE6: B6.D5, R42.2, U6.4
SPI_CIPO: B1.D12, JP2.3
SPI_CIPO1: B2.D12, JP9.3
SPI_CIPO2: B3.D12, JP15.3
SPI_CIPO3: B4.D12, JP21.3
SPI_CIPO4: B5.D12, JP27.3
SPI_CIPO5: B6.D12, JP33.3
SPI_COPI: B1.D11, JP3.3
SPI_COPI1: B2.D11, JP10.3
SPI_COPI2: B3.D11, JP16.3
SPI_COPI3: B4.D11, JP22.3
SPI_COPI4: B5.D11, JP28.3
SPI_COPI5: B6.D11, JP34.3
SPI_CS: B1.D10, JP4.3
SPI_CS1: B2.D10, JP11.3
SPI_CS2: B3.D10, JP17.3
SPI_CS3: B4.D10, JP23.3
SPI_CS4: B5.D10, JP29.3
SPI_CS5: B6.D10, JP35.3
SPI_SCK: B1.D13, JP5.3
SPI_SCK1: B2.D13, JP12.3
SPI_SCK2: B3.D13, JP18.3
SPI_SCK3: B4.D13, JP24.3
SPI_SCK4: B5.D13, JP30.3
SPI_SCK5: B6.D13, JP36.3
TCLK: J1.4, TP1.1, U1.8
TCLK1: J6.4, TP2.1, U2.8
TCLK2: J11.4, TP3.1, U3.8
TCLK3: J16.4, TP4.1, U4.8
TCLK4: J21.4, TP5.1, U5.8
TCLK5: J26.4, TP6.1, U6.8
TMS: J1.2, U1.7
TMS1: J6.2, U2.7
TMS2: J11.2, U3.7
TMS3: J16.2, U4.7
TMS4: J21.2, U5.7
TMS5: J26.2, U6.7
U0RXI: J2.3, U1.13
U0RXI1: J7.3, U2.13
U0RXI2: J12.3, U3.13
U0RXI3: J17.3, U4.13
U0RXI4: J22.3, U5.13
U0RXI5: J27.3, U6.13
U0TXO: J2.2, U1.12
U0TXO1: J7.2, U2.12
U0TXO2: J12.2, U3.12
U0TXO3: J17.2, U4.12
U0TXO4: J22.2, U5.12
U0TXO5: J27.2, U6.12
U1RXI: S1.5, U1.28
U1RXI1: S4.5, U2.28
U1RXI2: S7.5, U3.28
U1RXI3: S10.5, U4.28
U1RXI4: S13.5, U5.28
U1RXI5: S16.5, U6.28
U1TXO: S1.2, U1.29
U1TXO1: S4.2, U2.29
U1TXO2: S7.2, U3.29
U1TXO3: S10.2, U4.29
U1TXO4: S13.2, U5.29
U1TXO5: S16.2, U6.29

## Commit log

2021-07-26 V10 Dialog Changes
    - GPIOA6 needs 4.7k Pullup
    - GPIOA10 - added 2-way jumper for MCU (SPI Interrupt) and Header (PWM)
    - GPIOC6,7,8 not needed for JTAG
    - Removed RTC Sensor, RTC_WAKE1, RTC_WAKE2
    - PCB - Moved VDD trace, enlarged ground connection for RF GND on bottom, added more vias in large ground areas
    [SparkFun WiFi Shield - DA16200.brd, SparkFun WiFi Shield - DA16200.sch]
2021-07-26 Parts Update
    Updated library for module, added 470k resistor, updated symbols, added jumper notes
    [SparkFun WiFi Shield - DA16200.brd, SparkFun WiFi Shield - DA16200.sch]
2021-07-27 Added I2C
    Added I2C connections, Qwiic connector, pullup resistors, and jumper
    [SparkFun WiFi Shield - DA16200.brd, SparkFun WiFi Shield - DA16200.sch]
2021-07-27 V10 Design Review Changes
    Updated label positions, added notes to sch
    [SparkFun WiFi Shield - DA16200.brd, SparkFun WiFi Shield - DA16200.sch]
2021-07-28 Final Feedback Changes
    Changed R3 footprint to locking
    Added DNP Capacitor and Resistor
    [SparkFun WiFi Shield - DA16200.brd, SparkFun WiFi Shield - DA16200.sch]
2021-07-29 Added jumpers for GPIOA0-3
    Jumpers select between either SPI or GPIO/ADC functionality on the DA16200
    [SparkFun WiFi Shield - DA16200.brd, SparkFun WiFi Shield - DA16200.sch]
2021-07-30 Update SparkFun WiFi Shield - DA16200.brd
    Updated vias
    [SparkFun WiFi Shield - DA16200.brd]
2021-08-03 Added Gerbers
    [SparkFun WiFi Shield - DA16200-Panel.GBL, SparkFun WiFi Shield - DA16200-Panel.GBO, SparkFun WiFi Shield - DA16200-Panel.GBP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]
2021-08-05 Panel update
    Moved fiducials away from v-score
    [SparkFun WiFi Shield - DA16200-Panel.brd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]
2021-08-10 Update SparkFun WiFi Shield - DA16200.sch
    Fixed typo for JP3
    [SparkFun WiFi Shield - DA16200.sch]

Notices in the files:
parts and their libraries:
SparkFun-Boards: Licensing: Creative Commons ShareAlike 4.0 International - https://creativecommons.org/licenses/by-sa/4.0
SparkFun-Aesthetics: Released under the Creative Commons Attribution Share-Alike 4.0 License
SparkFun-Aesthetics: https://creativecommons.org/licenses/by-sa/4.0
